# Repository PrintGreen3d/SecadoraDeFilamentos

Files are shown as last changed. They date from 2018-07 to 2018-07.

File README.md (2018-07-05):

# Estufa Secagem

A grande maioria dos polímeros são higroscópicos ou seja é uma característica de determinados materiais plásticos que diz respeito à capacidade de eles absorverem água. Na industria é uma pratica comum "secar" o material e quanto mais água absorvem, mais tempo permanecem no funil alimentador secador para que sejam desumidificados antes de serem utilizados.

# Versão Anteriores	

No desenvolvimento tive 2 versão a [primeira versão](https://github.com/PrintGreen3d/retiraUmidade-V0.1), usei uma caixa de papelão, secador de cabelo, lm35 e um arduino para fazer o controle de temperatura.

# Versão Atual	
Nesta versão reciclei uma estufa antiga de dentista. A mesma tem pelo menos 19 anos e não existe mais peças de reposição, as poucas que encontrei o preço foi fora do orçamento, decidi remover as peças antigas e instalar um lcd e controle de temperatura e tempo na estufa. 

## Pastas

O Projeto conta com 3 pastas

 - Codigo fonte do arduino;
 - Arquivos OpenSCAD do case do lcd;
 - Arquivos para confecção de uma placa de controle. 

## Componentes
- Arduino Uno/Nano
- Lm35
- Lcd 4 vias i2c
- rtc3231
- Potenciômetro 10k
- Botão

## Video 
O funcionamento atual pode ser visto neste link:

https://youtu.be/8OtH3Y8lwzA

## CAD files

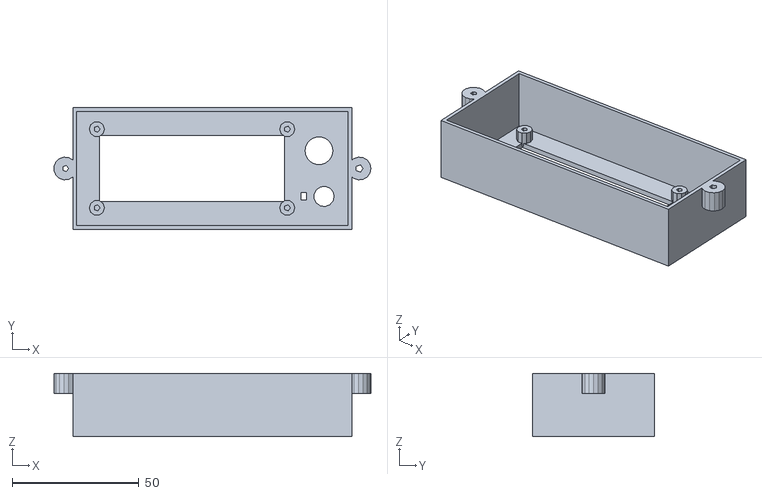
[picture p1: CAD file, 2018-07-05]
LCD/lcd_da_Estufa.stl
124.9 x 48.0 x 25.0

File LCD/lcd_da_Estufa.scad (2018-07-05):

fn=100;


module pot() {
  cylinder(d=18, h=8, $fs=0.01, center = true);
  translate([0,8,3.5]) 
      cube([15,7,1], center = true);
  lug([0,12,3.75]);
  lug([6,12,3.75]);
  lug([-6,12,3.75]);
  difference() {
    translate([0,0,4.5]) 
        cylinder(d=10, h=1, center = true, $fs=0.01);
    translate([0,6.25,4.701])
        cube([8,4,1.5], center = true);    
    translate([0,-6,4.701])
        cube([8,4,1.5], center = true); 
  }
  translate([0,0,8])
      cylinder(d=7, h=6, center = true, $fs=0.01);
  difference() {
    translate([0,0,14])
        cylinder(d=6.5, h=10, center = true, $fs=0.01);
    translate([0,0,14])
        cube([7,1,11], center = true);
  }
  translate([8.25,0,5])
    cube([1,2,2],center=true);

}

module lug(translate) {
  translate(translate) 
      cube([1.25,1,0.5], center = true);
  translate(translate) 
      translate([0,0.75,-0.25]) 
      rotate([90,0,0]) 
      cube([1.25,1,0.5], center = true);

  difference() {
    translate(translate) 
        translate([0,0.75,-2.75]) 
        rotate([90,0,0])
        cube([3,4,0.5], center = true);
    translate(translate) 
        translate([0,0.75,-2.75]) 
        rotate([90,0,0])
        cube([1,2,1], center = true);
  }
}


module Exemplo()
{
//shape = "flat"; 
shape = "angle";

// outer size
boxx = 86;
boxy = 41;   // internal size = 41-2*1.5 = 38.0
boxz = 21;

wall = 1.5;

// LCD pcb
//pcblcdx = 80;
//pcblcdy = 36;
//pcblcdz = 1.8;  //thichness off PCB

// distance between LCD PCB screws
lcdscrewx = 75; 
lcdscrewy = 31;

// window for LCD
lcdx    = 72;
lcdy    = 25;

// LCD mounting holes
standz  =   5;        // height of the standoff
standr  = 2.5;       // 5 mm diameter
screwz = standz;  // depth of srew hole
screwr = 1.5;       // 3 mm hole size

// 4 pole connector size
cony =   10 + 1;
conz =  2.5 + 1;

conlocz = 8.5+standz;  // 8.5 mm above pcb
conlocy = 2; // 2 mm from centre of hole

$fn=12;


// make the module
translate([-boxx/2,-boxy/2,0]) frontplate();

// view only
//translate([-boxx/2,-boxy/2,boxz+10])# bottom();

// print bottom
//if (shape == "flat")
//    	{rotate([0,180,0])  translate([-boxx/2,-boxy/2,-wall])  bottom();}
//	else
//	{translate([boxx/2,-boxy/2,wall])  rotate([20,180,0])  bottom();}



// make standoff for LCD pcb
// ------------------------------
module standoff()
	{difference()
		{translate([0,0,0]) cylinder(r=standr,h=standz+wall);
		  translate([0,0,wall+standz-screwz]) cylinder(r=screwr,h=screwz+0.1);
		}
	}




// LCD case
// --------------------------
module frontplate()
	{difference()
		{ if (shape=="flat") {cube([boxx,boxy,boxz]);}
                     else                 {cube([boxx,boxy,boxz+20]);}

		// empty the inside of the box
		  translate([wall,wall,wall]) cube([boxx-2*wall,boxy-2*wall,boxz+20]); 

		// make LCD window
	 	  translate([(boxx-lcdx)/2,(boxy-lcdy)/2,-wall]) cube([lcdx,lcdy,3*wall]);

		// make hole for connector
		  translate([-wall,conlocy+(boxy-lcdscrewy)/2,conlocz+wall]) cube([3*wall,cony,conz]);

		// make box with angle 20 degrees
		if (shape == "angle")                              // remove part of the top
			{translate([-5,-5,29]) rotate([-20,0,0]) cube([boxx+10,boxy+10,boxz+10]); }

		}


// standoffs for LCD PCB
	translate([                (boxx-lcdscrewx)/2,                (boxy-lcdscrewy)/2,0]) standoff(); 
	translate([                (boxx-lcdscrewx)/2,lcdscrewy+(boxy-lcdscrewy)/2,0]) standoff();
	translate([lcdscrewx+(boxx-lcdscrewx)/2,                (boxy-lcdscrewy)/2,0]) standoff();
	translate([lcdscrewx+(boxx-lcdscrewx)/2,lcdscrewy+(boxy-lcdscrewy)/2,0]) standoff();


	}


// LCD bottom
// ---------------------------
module bottom()
	{ if (shape=="flat")
		{difference()
			{union()
				{cube([boxx,boxy,wall]);
	   		 	translate([wall,wall,-2]) cube([boxx-2*wall,boxy-2*wall,2+wall]);
				}
			translate([2*wall,2*wall,-2.1]) cube([boxx-4*wall,boxy-4*wall,2.1]);

			// remove the corners
			translate([0,0,-2.1]) cube([25,15,2.1]);
			translate([boxx-25,0,-2.1]) cube([25,15,2.1]);	
			translate([0,boxy-15,-2.1]) cube([25,15,2.1]);	
			translate([boxx-25,boxy-15,-2.1]) cube([25,15,2.1]);	
			}
		}
	   else { rotate([-20,0,0]) cube([boxx,boxy+3,wall]); 
		     translate([boxx/2-15,wall,            -wall-1.5]) cube([30,2,3]);
		     translate([boxx/2-15,boxy-wall-2,-16])          cube([30,2,3]);

		     translate([wall,22,-10]) rotate([-20,0,0])  cube([2,15,3]);	// con side
		     translate([boxx-wall-2,10,-6]) rotate([-20,0,0])  cube([2,25,3]);	
		   } // end of else			
	}

}
module lcdEstufa()
{
    difference()
    {
        color("red")cube([110,48,25],center =true);
        translate([0,0,2])
        color("green")cube([107,45,25],center =true);
    
        //LCD
        translate([-8,0,0]) 
        cube([73,26,50],center =true);
        
        //Potenciometro
        translate([44,-11,0])
        cylinder (h = 50, r=(8/2), center = true);
        translate([36,-11,0])
        cube([2,3,50],center =true);
        //translate([50,-11,0])
        //cube([2,3,50],center =true);
        
        //Botão
        translate([42,7,0])
        cylinder (h = 50, r=(11/2), center = true);
    }
}


module fixador()
{
    difference()
    {
        translate([-45.5,-15.5,-9])
        cylinder (h = 6, r=(6/2), center = true,fn=100);
        translate([-45.5,-15.5,-9])
        cylinder (h = 8, r=(2.5/2), center = true,fn=100);
    } 
    
    difference()
    {
        translate([-45.5,15.5,-9])
        cylinder (h = 6, r=(6/2), center = true,fn=100);
        translate([-45.5,15.5,-9])
        cylinder (h = 8, r=(2.5/2), center = true,fn=100);
    }
    
    difference()
    {
        translate([29.5,-15.5,-9])
        cylinder (h = 6, r=(6/2), center = true,fn=100);
        translate([29.5,-15.5,-9])
        cylinder (h = 8, r=(2.5/2), center = true,fn=100);
    }
    
    difference()
    {
        translate([29.5,15.5,-9])
        cylinder (h = 6, r=(6/2), center = true,fn=100);
        translate([29.5,15.5,-9])
        cylinder (h = 8, r=(2.5/2), center = true,fn=100);
    }
}

module fixadorLataria()
{
    difference()
    {
        translate([-58,0,8.5])
        cylinder (h = 8, r=(9/2), center = true,fn=100);
        translate([-57.9,0,4.5])
        cylinder (h = 60, r=(2.5/2), center = true,fn=100);
    } 
    
    difference()
    {
        translate([58,0,8.5])
        cylinder (h = 8, r=(9/2), center = true,fn=100);
        translate([57.9,0,2.5])
        cylinder (h = 60, r=(3/2), center = true,fn=100);
    }
}
union()
{
    
    
    lcdEstufa();
    fixador();
    fixadorLataria();
    //translate([44,-11,-4])
    //rotate([0,180,0])
    //pot();
   
    
}

//translate([-8,0,-10])
//Exemplo();

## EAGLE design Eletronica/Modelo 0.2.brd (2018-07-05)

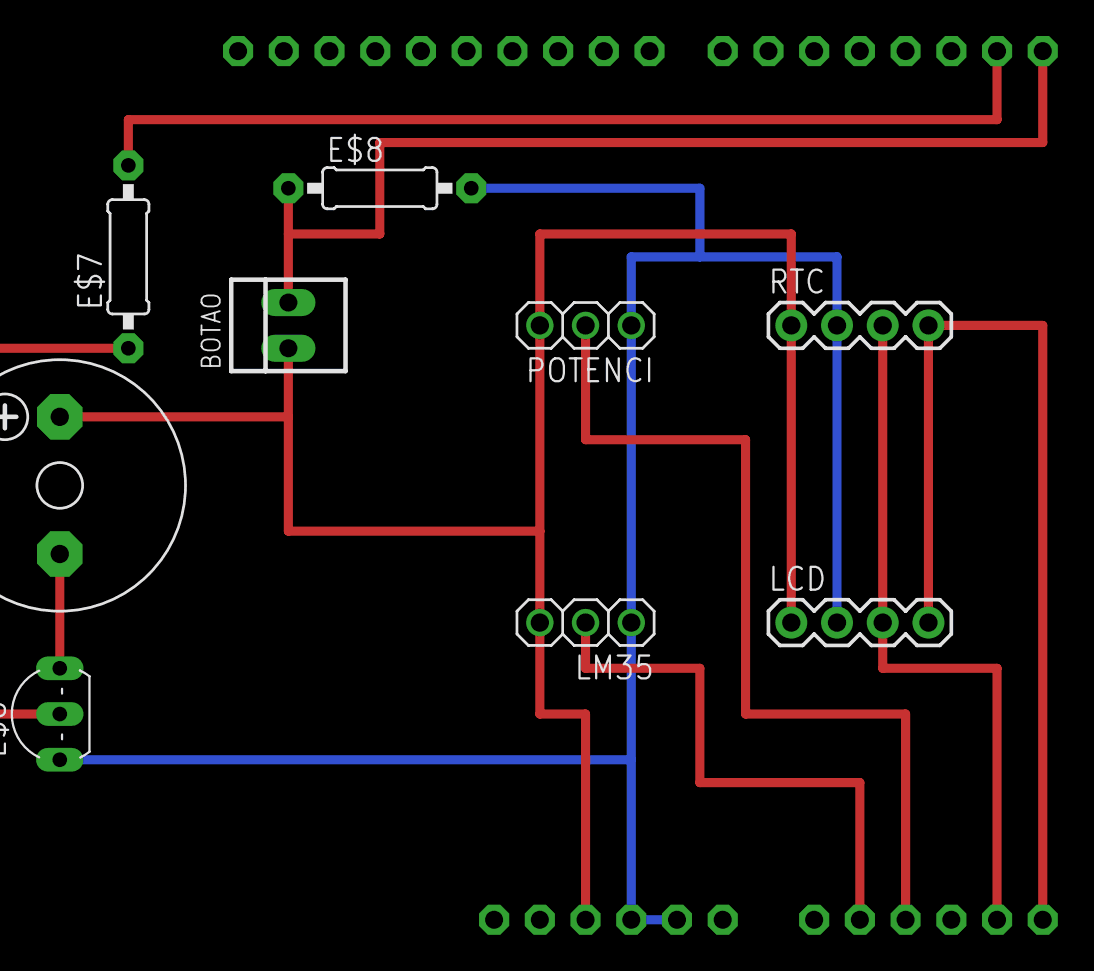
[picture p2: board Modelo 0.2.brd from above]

Board: 2 copper layers, 10 parts (0 on the bottom side), 10 nets.

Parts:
BOTAO: 22-23-2021
E$1: ARDUINOR3-NOTEXT-NOIOREF
E$6: TO92-OVAL
E$7, E$8: 0207/10
E$9: F/CM12P
LCD: 1X04-BIG
LM35: 1X03
POTENCI: 1X03
RTC: 1X04-BIG

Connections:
S$1: E$1.A5, LCD.4, RTC.4
S$2: E$1.A4, LCD.3, RTC.3
S$3: E$1.GND1, E$1.GND2, E$6.1, E$8.2, LCD.2, LM35.1, POTENCI.1, RTC.2
S$4: BOTAO.1, E$1.5V, E$9.+, LCD.1, LM35.3, POTENCI.3, RTC.1
S$5: E$1.A2, POTENCI.2
S$6: E$1.A1, LM35.2
S$7: BOTAO.2, E$1.D0, E$8.1
S$8: E$6.3, E$9.-
S$9: E$1.D1, E$7.2
S$10: E$6.2, E$7.1

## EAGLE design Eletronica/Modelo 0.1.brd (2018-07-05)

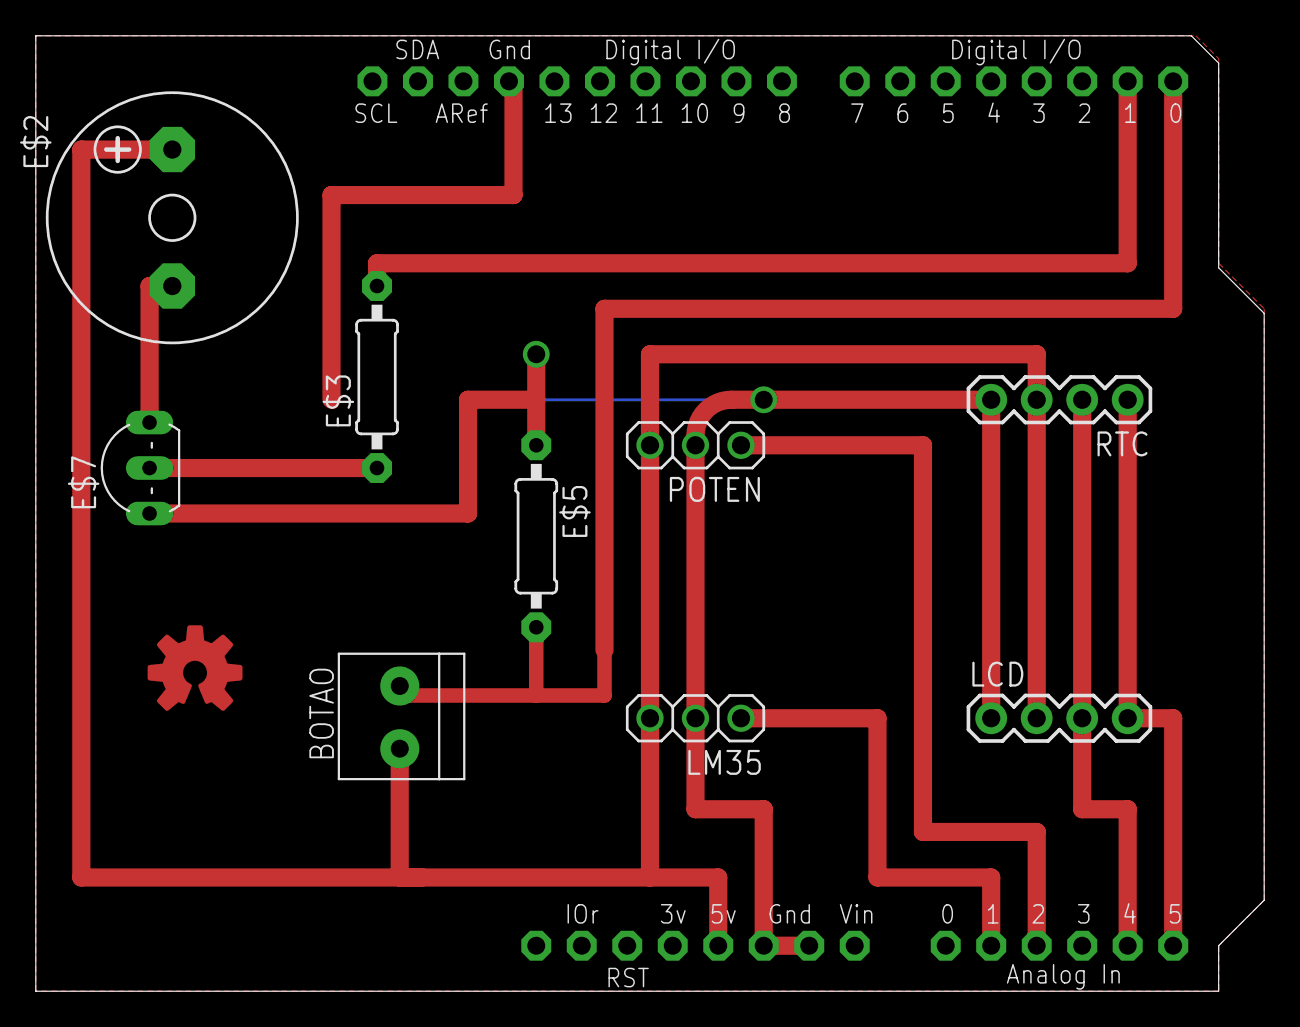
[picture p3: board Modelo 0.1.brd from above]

Board: 2 copper layers, 68.6 x 53.3 mm, 11 parts (0 on the bottom side), 10 nets.

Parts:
BOTAO: 1X2-3.5MM
E$1: ARDUINOR3
E$2: F/CM12P
E$3, E$5: 0207/10
E$4: OSHWLOGO_TOP_0.2
E$7: TO92-EBC-OVAL
LCD: 1X04-BIG
LM35: 1X03
POTEN: 1X03
RTC: 1X04-BIG

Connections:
GND: E$1.GND1, E$1.GND2, E$5.1, E$7.E, LCD.1, LM35.2, POTEN.2, RTC.4
S$1: E$1.5V, LCD.2, LM35.3, POTEN.3, RTC.3
S$2: E$3.1, E$7.B
S$3: E$1.A1, LM35.1
S$4: E$1.D0, E$5.2
S$5: E$1.D1, E$3.2
S$6: E$1.A2, POTEN.1
S$7: E$1.A5, LCD.4, RTC.1
S$8: E$1.A4, LCD.3, RTC.2
S$9: E$2.-, E$7.C

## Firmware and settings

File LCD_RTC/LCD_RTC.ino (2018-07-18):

/*
 * Sistema de controle da estufa 
 * Version: 2.0
 * 24/Novembro/2017
 * Hardware: 
 *            - Arduino Uno
 *            - RTC
 *            - LCD 16x2 I2C
 *            - Shield Rele 4 
 *            - Potenciometro 10k
 *            - Button
 *            - LM35
 * Software:
 *          O sistema ira ter uma tela de inicialão, após essa tela teremos uma que mostra dia, mes ano e horas.
 * 
 */

#include <Wire.h>
#include <LiquidCrystal_I2C.h>
#include "RTClib.h"

// Inicializa o display no endereco 0x27
LiquidCrystal_I2C lcd(0x27, 2, 1, 0, 4, 5, 6, 7, 3, POSITIVE);
byte zero = 0x00;


// Modulo RTC no endereco 0x68
RTC_DS3231 rtc;
char daysOfTheWeek[7][12] = {"Domingo", "Segunda", "Terca", "Quarta", "Quinta", "Sexta", "Sabado"};


// Definição de Variaveis e Porta utilizadas
const int LM35    = A1;  // Define o pino que lera a saída do LM35
const int Rele    = 5;   // Define o pino que é usado para desativar o rele
float temperatura = 0;   // Variável que armazenará a temperatura medida
int Potenciometro = A2;  // center pin of the potentiometer
const int Enter   = 2;   // Botão de Seleção
int buttonState   = 0;   // variable for reading the pushbutton status
int StatusEnter   = 0;
const int ledPin  = 13;  // the number of the LED pin
int opcaoSwitch   = 0;
int meuArray[3] = {NULL};

/*
 * CapturaTemperatura
 * Lê a porta A0 (sensor lm35) 20 vezes, após essa captura faz os calculos e divide pela quantidade de vezes capturada
 */
float CapturaTemperatura()
{
   float leitura[50] = {0}; // Armazena valores recolhidos pelo sensor
   float armazena = 0;

   //Faz a captura de valores
   for (int i = 0; i < 50; i++) 
   {
      delay(100);
      // leitura[i] = ((float(analogRead(LM35)) * 5 / (1023)) / 0.01);
      leitura[i] = (float( 5.0 * analogRead(LM35) * 100.0) / 1024.0);
      delay(100);
  }
  
  //Soma o array de valores capturados
  for (int i = 0; i < 50; i++) 
  {
    armazena = armazena + leitura[i];
  }
  // Media de temperatura (todos os valores somados dividido pela quantidade)
  armazena = (armazena / 50);
  return armazena;
}

byte ConverteParaBCD(byte val)
{ 
  //Converte o número de decimal para BCD
  return ( (val/10*16) + (val%10) );
}

byte ConverteparaDecimal(byte val)  
{ 
  //Converte de BCD para decimal
  return ( (val/16*10) + (val%16) );
}


int pegaHora ()
{
  
  meuArray[3] = {NULL};
  // Le os valores (data e hora) do modulo DS1307
  Wire.beginTransmission(DS1307_ADDRESS);
  Wire.write(zero);
  Wire.endTransmission();
  Wire.requestFrom(DS1307_ADDRESS, 7);
  meuArray[0] = ConverteparaDecimal(Wire.read());
  meuArray[1] = ConverteparaDecimal(Wire.read());
  meuArray[2] = ConverteparaDecimal(Wire.read() & 0b111111);
  
}


void MostraHora()
{
  // Refazer esta função - Jeito mais facil que pensei no momento, passar os valores como array, e trabalhar com eles 
  // tomara que não estrague tudo.
  // Fazer backup dessa versão antes de alterar.
  
  // Le os valores (data e hora) do modulo DS3231
  DateTime now = rtc.now();
  pegaHora ();
  int horas        = meuArray[2];
  int minutos      = meuArray[1]; 
  int segundos     = meuArray[0];
  int controleTela = 0;

  //Comprimenta
  if((horas >= 1) && (horas <=12))
  {
     if(controleTela == 1)
     {
        lcd.clear();
     }
     lcd.setCursor(0,0);
     lcd.print("Bom dia!");
  }
  else if((horas >= 13) && (horas <=18))
  {
     
     lcd.setCursor(0,0);
     lcd.print("Boa Tarde!");
     controleTela = 0;
  }
  else
  {
     lcd.setCursor(0,0);
     lcd.print("Boa Noite!");
     controleTela = 1;
  }


  // Mostra hora no display
  lcd.setCursor(10,0);
  lcd.print(" ");
  //Acrescenta o 0 (zero) se a hora for menor do que 10
  if (horas <10)
    lcd.print("0");
    lcd.print(horas);
    lcd.print(":");
  //Acrescenta o 0 (zero) se minutos for menor do que 10
  if (minutos < 10)
     lcd.print("0");
     lcd.print(minutos);
     lcd.setCursor(2,1);
     
  //Mostra o dia da semana

  lcd.setCursor(3,1);
  lcd.print(now.day(), DEC);
  lcd.print("/");
  lcd.print(now.month(), DEC);
  lcd.print("/");
  lcd.print(now.year(), DEC);
}

int MostraPosicao()
{
    int sensorValue = map(analogRead(Potenciometro), 0, 1025, 1, 50);
    // int pot = map(analogRead(potPin), 0, 1025, 1, 50);
    delay (300);
    return (sensorValue);
}


int ajusteManual(int limiteMenor, int limiteMaior)
{
    int sensorValue = map(analogRead(Potenciometro), 0, 1025, limiteMenor, limiteMaior);
    // int pot = map(analogRead(potPin), 0, 1025, 1, 1000);
    delay (100);
    return (sensorValue);
}

int ajusteTempo()
{
    int sensorValue = map(analogRead(Potenciometro), 0, 1025, 1, 11);
    // int pot = map(analogRead(potPin), 0, 1025, 1, 1000);
    delay (300);
    return (sensorValue);
}






void montaTelaAquecimento( int temperaturaMaxima, int temperaturaMinima, int tempoAquecimento)
{
  // https://forum.arduino.cc/index.php?PHPSESSID=d30237rgtla7qogj3i94e616j7&topic=86907.15
    
  int horaFinal[3]    = {NULL};
  int horaInicial[3]  = {NULL};
  long diferencaTempo = NULL;
  long inicioTempo    = NULL;
  long fimTempo       = NULL;
  
  

  //Liga o Rele
  digitalWrite(Rele, HIGH); // Liga o Rele para esfriar a estufa
  digitalWrite(LED_BUILTIN, LOW);
  lcd.clear();


  //Acrescenta o tempo de secagem ao horario atual
  pegaHora();
  horaFinal[0] = meuArray[0];
  horaFinal[1] = meuArray[1]; 
  horaFinal[2]= meuArray[2] + tempoAquecimento;
  
  //Verifica a primeira vez a hora antes de entrar em loop
  pegaHora();
  horaInicial[0] = meuArray[0];
  horaInicial[1] = meuArray[1]; 
  horaInicial[2] = meuArray[2];
  

  // Converte o tempo para segundos e calcula a diferença
  inicioTempo = horaInicial[2]*3600 + horaInicial[1] * 60 + horaInicial[0];
  fimTempo    = horaFinal[2]*3600 + horaFinal[1] * 60 + horaFinal[0];
  diferencaTempo= fimTempo- inicioTempo;

  while(diferencaTempo >= 0)
  {
    
    digitalWrite(Rele, HIGH); // Inicio do aquecimento

    //Zera as variaveis utilizadas
    temperatura    = NULL;
    horaInicial[0] = NULL;
    horaInicial[1] = NULL; 
    horaInicial[2] = NULL;

    
    // Le os valores (data e hora) do modulo DS1307
    pegaHora();
    horaInicial[0] = meuArray[0];
    horaInicial[1] = meuArray[1]; 
    horaInicial[2] = meuArray[2];

    // Captura a temperatura atual para mostrar no display  
    temperatura = CapturaTemperatura();
    
    lcd.setCursor(0,0);
    lcd.print("Temp: ");
    lcd.setCursor(5, 0);
    lcd.print(temperatura);
    lcd.setCursor(14, 0);
    lcd.print("AQ");
    lcd.setCursor(0,1);
    lcd.print("A:");
    lcd.setCursor(2,1);
    
    //Acrescenta o 0 (zero) se a hora for menor do que 10
    if (horaInicial[2] <10)
    lcd.print("0");
    lcd.print(horaInicial[2]);
    lcd.print(":");

    //Acrescenta o 0 (zero) se minutos for menor do que 10
    if (horaInicial[1] < 10)
    lcd.print("0");
    lcd.print(horaInicial[1]);
    lcd.setCursor(9,1);
    
    // Mostra o horario de termino da secagem
    lcd.print("F:");
    //Acrescenta o 0 (zero) se a hora for menor do que 10
    if (horaFinal[2] <10)
    lcd.print("0");
    lcd.print(horaFinal[2]);
    lcd.print(":");
    //Acrescenta o 0 (zero) se minutos for menor do que 10
    if (horaFinal[1] <10)
    lcd.print("0");
    lcd.print(horaFinal[1]);

    if (temperatura >= temperaturaMaxima)
    {
      temperatura = 0;
      digitalWrite(Rele, LOW); // Desliga o Rele para esfriar a estufa
      digitalWrite(LED_BUILTIN, LOW);
      lcd.setBacklight(HIGH);
      lcd.setCursor(14, 0);
      lcd.print("ES");
      
      do{
          temperatura = CapturaTemperatura();
          lcd.setCursor(0,0);
          lcd.print("Temp: ");
          lcd.setCursor(5, 0);
          lcd.print(temperatura);
          
          //Atualiza a hora atua
          horaInicial[0] = NULL;
          horaInicial[1] = NULL; 
          horaInicial[2] = NULL;
          // Le os valores (data e hora) do modulo DS1307
          pegaHora();
          horaInicial[0] = meuArray[0];
          horaInicial[1] = meuArray[1]; 
          horaInicial[2] = meuArray[2];
          //Mostra no Display a hora atual
          
          
          lcd.setCursor(0,1);
          lcd.print("A:");
          lcd.setCursor(2,1);
          //Acrescenta o 0 (zero) se a hora for menor do que 10
          if (horaInicial[2] <10)
              lcd.print("0");
          lcd.print(horaInicial[2]);
          lcd.print(":");

          //Acrescenta o 0 (zero) se minutos for menor do que 10
          if (horaInicial[1] < 10)
              lcd.print("0");
          lcd.print(horaInicial[1]);
          delay(200);

          //Atualiza valores para verificar se continua em loop
          horaInicial[0] = NULL;
          horaInicial[1] = NULL; 
          horaInicial[2] = NULL;
          diferencaTempo = NULL;
    
          // Le os valores (data e hora) do modulo DS1307
          pegaHora();
          horaInicial[0] = meuArray[0];
          horaInicial[1] = meuArray[1]; 
          horaInicial[2] = meuArray[2];
          inicioTempo = horaInicial[2]*3600 + horaInicial[1] * 60 + horaInicial[0];
          diferencaTempo= fimTempo- inicioTempo;

          if(diferencaTempo <= 0)
          {
            break;
          }




          
          
      }while(temperatura > temperaturaMinima);
    }
    //Atualiza valores para verificar se continua em loop
    horaInicial[0] = NULL;
    horaInicial[1] = NULL; 
    horaInicial[2] = NULL;
    diferencaTempo = NULL;
    
    // Le os valores (data e hora) do modulo DS1307
    pegaHora();
    horaInicial[0] = meuArray[0];
    horaInicial[1] = meuArray[1]; 
    horaInicial[2] = meuArray[2];
    inicioTempo = horaInicial[2]*3600 + horaInicial[1] * 60 + horaInicial[0];
    diferencaTempo= fimTempo- inicioTempo;
   
    
  }// Fim do While
    
    lcd.clear();
    lcd.print("Fim do aquecimento....");
    lcd.setCursor(0,1);
    lcd.print("Desligando estufa!");
    digitalWrite(Rele, LOW); // Desliga o Rele para esfriar a estufa
    digitalWrite(LED_BUILTIN, LOW);
    // Implentar função do buzzer

    // Limpeza de todas as variaveis usadas
    horaInicial[0]  = NULL;
    horaInicial[1]  = NULL; 
    horaInicial[2]  = NULL;
    diferencaTempo  = NULL;
    horaFinal[3]    = {NULL};
    horaInicial[3]  = {NULL};
    diferencaTempo  = NULL;
    inicioTempo     = NULL;
    fimTempo        = NULL;
    
    delay(500);
}


void montaTelaAjusteManual()
{
  int prendeLoop       = 3;
  int potenciometro    = 0;
  int temperaturaSel   = 0;
  int tempoSelecionado = 0;
  
  while(prendeLoop != 0)
  {
    
    lcd.clear();
    lcd.setCursor(0,0);
    lcd.print("Temperatura:");
    potenciometro = ajusteManual(0,250);
    lcd.setCursor(0,1);
    lcd.print(potenciometro);
    delay(1800);     
     // Verifica se o botão foi pressionado
    buttonState = digitalRead(Enter);
    //Se sim a entrada do arduino muda para Ligada (HIGH)
    if (buttonState == HIGH) 
    {
      
      temperaturaSel = potenciometro;
      prendeLoop     = 0;
    }
  }

  
  potenciometro = NULL;
  prendeLoop     = 4;
  
  while(prendeLoop != 0)
  {
    
    lcd.clear();
    lcd.setCursor(0,0);
    lcd.print("Tempo (h):");
    potenciometro = ajusteTempo();
    lcd.setCursor(0,1);
    lcd.print(potenciometro);
    delay(1800);     
     // Verifica se o botão foi pressionado
    buttonState = digitalRead(Enter);
    //Se sim a entrada do arduino muda para Ligada (HIGH)
    if (buttonState == HIGH) 
    {
      
      tempoSelecionado = potenciometro;
      prendeLoop     = 0;
    }
  }

  lcd.clear();
  lcd.setCursor(0,0);
  lcd.print("Temperatura:");
  lcd.setCursor(12,0);
  lcd.print(temperaturaSel);
  lcd.setCursor(0,1);
  lcd.print("Tempo (H):");
  lcd.setCursor(12,1);
  lcd.print(tempoSelecionado);
  delay(3000);
  montaTelaAquecimento(temperaturaSel,(temperaturaSel-10),tempoSelecionado);
  
}


void ajustaDataHora()
{
  int ajusteHora    = 0;
  int ajusteminuto  = 0;
  int ajusteSegundo = 0;
  int ajusteDia     = 0;
  int ajusteMes     = 0;
  int ajusteAno     = 0;
  int prendeLoop    = 6;
  int potenciometro = 0;


  while(prendeLoop != 0)
  {
    
    lcd.clear();
    lcd.setCursor(0,0);
    lcd.print("Hora Atual:");
    potenciometro = ajusteManual(0,27);
    lcd.setCursor(0,1);
    lcd.print(potenciometro);
    delay(1800);     
     // Verifica se o botão foi pressionado
    buttonState = digitalRead(Enter);
    //Se sim a entrada do arduino muda para Ligada (HIGH)
    if (buttonState == HIGH) 
    {
      
      ajusteHora = potenciometro;
      prendeLoop     = 0;
    }
  }
  potenciometro = NULL;
  prendeLoop     = 4;

  while(prendeLoop != 0)
  {
    lcd.clear();
    lcd.setCursor(0,0);
    lcd.print("Hora Atual:");
    potenciometro = ajusteManual(0,69);
    lcd.setCursor(0,1);
    lcd.print(ajusteHora);
    lcd.print(":");    
    lcd.print(potenciometro);
    delay(1800);     
     // Verifica se o botão foi pressionado
    buttonState = digitalRead(Enter);
    //Se sim a entrada do arduino muda para Ligada (HIGH)
    if (buttonState == HIGH) 
    {
      
      ajusteminuto = potenciometro;
      prendeLoop     = 0;
    }
  }
  potenciometro = NULL;
  prendeLoop     = 6;
  lcd.clear();

  while(prendeLoop != 0)
  {
    
    lcd.clear();
    lcd.setCursor(0,0);
    lcd.print("Data Atual:");
    potenciometro = ajusteManual(1,36);
    lcd.setCursor(0,1);
    lcd.print(potenciometro);
    delay(1800);     
     // Verifica se o botão foi pressionado
    buttonState = digitalRead(Enter);
    //Se sim a entrada do arduino muda para Ligada (HIGH)
    if (buttonState == HIGH) 
    {
      
      ajusteDia  = potenciometro;
      prendeLoop = 0;
    }
  }

  potenciometro = NULL;
  prendeLoop     = 9;

  while(prendeLoop != 0)
  {
    lcd.clear();
    lcd.setCursor(0,0);
    lcd.print("Data Atual:");
    potenciometro = ajusteManual(1,14);
    lcd.setCursor(0,1);
    lcd.print(ajusteDia);
    lcd.print("/");
    lcd.print(potenciometro);
    delay(1800);     
     // Verifica se o botão foi pressionado
    buttonState = digitalRead(Enter);
    //Se sim a entrada do arduino muda para Ligada (HIGH)
    if (buttonState == HIGH) 
    {
      
      ajusteMes  = potenciometro;
      prendeLoop = 0;
    }
  }

  potenciometro = NULL;
  prendeLoop     = 26;

  while(prendeLoop != 0)
  {
    lcd.clear();
    lcd.setCursor(0,0);
    lcd.print("Data Atual:");

    lcd.setCursor(0,1);
    lcd.print(ajusteDia);
    lcd.print("/");
    lcd.print(ajusteMes);
    lcd.print("/");
    potenciometro = ajusteManual(2018,2040);
    lcd.print(potenciometro);
    delay(1800);     
     // Verifica se o botão foi pressionado
    buttonState = digitalRead(Enter);
    //Se sim a entrada do arduino muda para Ligada (HIGH)
    if (buttonState == HIGH) 
    {
      
      ajusteAno  = potenciometro;
      prendeLoop = 0;
    }
  }

  potenciometro = NULL;
  prendeLoop    = 0;

  lcd.clear();
  rtc.begin();
  rtc.lostPower();
  rtc.adjust(DateTime(ajusteAno, ajusteMes, ajusteDia, ajusteHora, ajusteminuto, 0));

  delay(3000);
  StatusEnter = 0;
  lcd.clear();
  MostraHora();
}


int meuMenuOperacional(int Opcao)
{
  switch (Opcao) {
    case 1:
      // Filamentos
      montaTelaAquecimento(60,55,2);
      delay(500);
      StatusEnter = 0;
      lcd.clear();
      break;
    case 2:
      //Granulos;      
      montaTelaAquecimento(80,75,4);
      delay(500);
      StatusEnter = 0;
      lcd.clear();
      break;
    case 3:
      montaTelaAjusteManual();
      delay(500);
      StatusEnter = 0;
      lcd.clear();
      break;
    case 4:
      ajustaDataHora();
      delay(500);
      StatusEnter = 0;
      lcd.clear();
    
    break;
    case 5:
    default:
      //Atribui o valor a variavel StatusEnter
      StatusEnter = 0;
      lcd.clear();
      MostraHora();
      break;
  }

  
}



void setup()
{
  //A linha é usada para acertar a Data e a Hora
  #ifndef ESP8266
    while (!Serial); // for Leonardo/Micro/Zero
  #endif

  if (! rtc.begin()) {
    Serial.println("Couldn't find RTC");
    while (1);
  }

  // Inicializa o botão de seleção (ENTER)
  pinMode(Enter, OUTPUT);
  pinMode(ledPin, OUTPUT);
  
  pinMode(Rele, OUTPUT);
  pinMode(LED_BUILTIN, OUTPUT);
  //analogReference(INTERNAL);
  lcd.setBacklight(HIGH);
  
  pinMode(7, OUTPUT);
  lcd.begin(20,4); //Inicialização do LCD 
  lcd.noBacklight();
  delay(250);
  lcd.backlight();
  lcd.setCursor(0,2);
  lcd.write(" Controle Estufa"); 
  lcd.setCursor(0,3);
  lcd.write("**PrintGreen3D**"); 
  //lcd.blink();
  delay(3000);
  lcd.noBlink(); 
  
  for (int i = 0; i < 20; i++) {
   delay(200);
   lcd.scrollDisplayLeft();
  }
  delay(2500);
  lcd.clear(); // Turns off the blinking cursor
}



void loop()
{
    int potencia = 0;
    //Inicia mostrando a Hora
    MostraHora();
    
    // Verifica se o botão foi pressionado
    buttonState = digitalRead(Enter);
    //Se sim a entrada do arduino muda para Ligada (HIGH)
    if (buttonState == HIGH) 
    {
      //Limpo o LCD    
      lcd.clear();
      //Atribui o valor a variavel StatusEnter
      StatusEnter = 1;
      delay (200);
      while(StatusEnter == 1)
      {
          potencia = MostraPosicao();

          if((potencia >=0) && (potencia <= 10))
          {
            lcd.clear();
            lcd.setCursor(0,0);
            lcd.print("> Filamentos");
            lcd.setCursor(0,1);
            lcd.print("  Granulos");
            opcaoSwitch = 1;
          }
          else if ((potencia >=11) && (potencia <= 20))
          {
            lcd.clear();
            lcd.setCursor(0,0);
            lcd.print("  Filamentos");
            lcd.setCursor(0,1);
            lcd.print("> Granulos");
            opcaoSwitch = 2;
          }

          else if ((potencia >=21) && (potencia <= 30))
          {
            lcd.clear();
            lcd.setCursor(0,0);
            lcd.print("  Granulos");
            lcd.setCursor(0,1);
            lcd.print("> Def. Manual");
            opcaoSwitch = 3;
          }
          else if ((potencia >=31) && (potencia <= 40))
          {
            lcd.clear();
            lcd.setCursor(0,0);
            lcd.print("  Def. Manual");
            lcd.setCursor(0,1);
            lcd.print("> Ajuste hora");
            opcaoSwitch = 4;
          }
          else
          {
            lcd.clear();
            lcd.setCursor(0,0);
            lcd.print("  Ajuste hora");
            lcd.setCursor(0,1);
            lcd.print("> Sair");
            opcaoSwitch = 5;
          }

            
           //Verifica o botão foi precionado novamente
          delay(200);
          buttonState = digitalRead(Enter);
          if (buttonState == HIGH) 
          {
            meuMenuOperacional(opcaoSwitch);
            delay(200); 
          }
      }// Fim do while          
    
    }   
}

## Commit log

2018-07-05 Primeira versão
    [Control Estufa.sch, Modelo 0.1.brd, Modelo 0.2.brd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]
2018-07-05 Subindo arquivo do arduino
2018-07-11 Ajuste de Hora e Data pelo LCD
2018-07-18 Correção de variaveis e de leitura do potenciometro
